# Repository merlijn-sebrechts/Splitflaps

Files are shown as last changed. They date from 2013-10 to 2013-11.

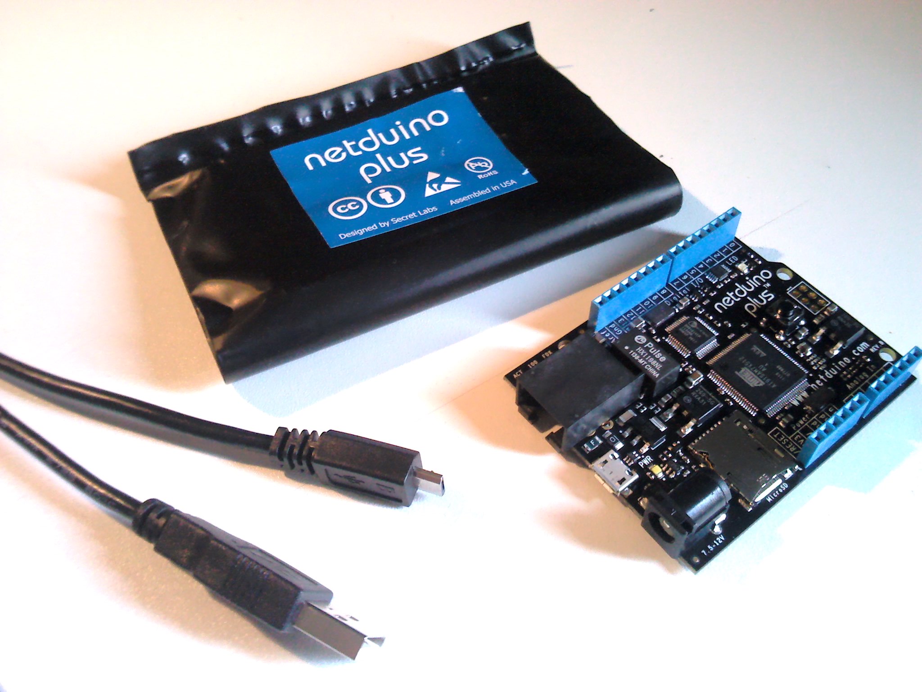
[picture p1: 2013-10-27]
documentation/Media/2012-03-29 13.55.59.jpg

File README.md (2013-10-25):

Splitflaps
==========
This project contains all the technical information I have from the SPLITFLAPS project.

I started this project as part of my studies, an continued to work on it after my studies. However, due to lack of time, I stopped working on it.

related:
http://splitflaps.wordpress.com/
http://www.0x20.be/Project_Flappers
https://www.youtube.com/user/Galgaleshe/videos

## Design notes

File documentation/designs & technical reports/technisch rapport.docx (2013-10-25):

# Microcontroller

## Netduino+

Netduino+ is een arduino microcontroller met het .net micro framework er op. Dit staat toe om je programma’s op het .net framework te laten draaien. Je kan daardoor programmeren in visual C# en alle andere talen ondersteund door het .net micro framework.

## .NET micro framework

Dit is een lichtere, kleinere versie van het .net framework. Doordat het zo licht is word bepaalde .net functionaliteit, zoals generische lijsten, niet ondersteund.

# Programma

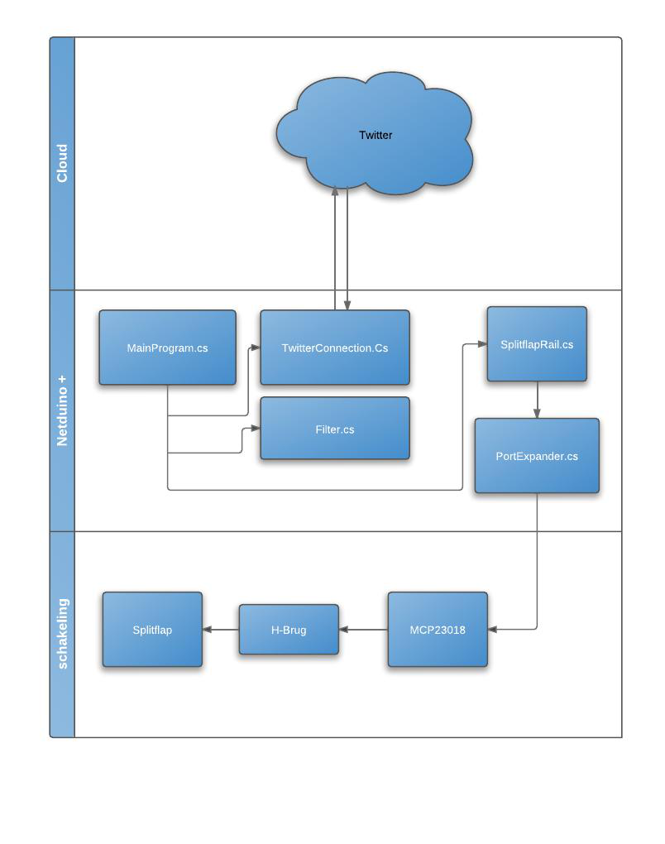
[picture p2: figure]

## Afhalen van Twitter

Dit deel wordt afgeschermd in de klasse TwitterConnection, allereerst wordt de klasse aangemaakt met een hashtag, deze wordt aan de zoekquery toegevoegd

(vb. http://search.twitter.com/search.json?q=%23ikdoeict)

Er zijn verschillende methoden gemaakt voor de zoekquery aan te passen zoals rpp (results per page) en since_id.

Deze methoden roepen een HttpWebRequest op met de URL, de HttpWebRequest zorgt ervoor dat we de query uitvoeren op de twitter server, en we nemen een antwoord op met WebResponse.

Het resultaat van die WebResponse, een json, wordt geparsed door een nieuwe methode,
het parsen gebeurd door middel van IndexOf en Substring.

Alle resultaten van de query (of als results per page = 1 (&rpp=1)) worden in een ArrayList geplaatst en doorgegeven aan de bovenliggende methoden, en die geeft ze dan terug aan de main loop.

## Filter

Deze klasse leest filter.txt in dat op een SD kaart staat. In dit tekst bestand staan alle woorden die verboden zijn in een tweet. Eerst wordt de tekst uit een tweet object gehaald. Vervolgens worden de woorden gesplit en vergeleken met de slechte. Wanneer er een overeenkomst is wordt de tweet niet gebruikt.

Daarna wordt ook op de leestekens gefilterd omdat de splitflaps maar beperkte tekens bevatten. Wanneer er een teken voorkomt wordt deze vervangen door een spatie (lege flap). Vervolgens wordt de tweet tekst opnieuw opgebouwd. Uiteindelijk wordt er een tweet object gereturned.

## Aansturing schakeling

### I2CPlug

Deze klasse voorziet alle functionaliteit van een I2C device. Lezen en schrijven + lezen en schrijven van een register. Deze klasse is gebruikt de repeated-start-bit functionaliteit en is dus niet geschikt voor I2C apparaten die dat niet ondersteunen. De clock-rate wordt automatisch gezet op 400Kh.

### PortexpanderPlug

Deze klasse erft over van de I2CPlug klasse en voorziet alle functionaliteit om de MCP23018 aan te sturen. In de contructor worden de pinnen automatisch op output gezet. Input is niet mogelijk.

Je geeft het adres van de chip mee met de constructor:
PortExpanderPlug(0x20);

Je schrijft een byte naar de pinnen (bit 0 = pin 0). Je geeft de kant van de MCP (A of B)

plug.WriteToPins(byte, Side);

Interne pullup wordt NIET aangezet, je moet die dus zelf nog aanzetten.

### SplitflapConfig

Deze klasse houdt data van de splitflap bij. De beschikbare karakters en hun plaats worden statish bijgehouden in de klasse. Verder wordt de plaats van de splitflap in de schakeling bijgehouden ahv portexpander adres, zijde van de portexpander en bit van de portexpander.

Het huidig getoonde karakter van de splitflap wordt ook bijgehouden. Bij het aanpassen van deze waarde wordt automatisch gekekekn of de splitflap een volledige toer heeft gemaakt. De waare wordt dan op 0 gezet.

### SplitflapRail

Maakt een array van SplitflapConfig-objecten.

De splitflap wordt 1 stap verzet door de betreffende bit van de portexpander te toggelen. Momenteel wordt iedere splitflap apart verzet. Na iedere bit te verzetten moet er een periode gewacht worden tot de flap mechanisch op de volgende positie staat. Dit stond eerst op 50ms maar we hebben de wachttijd moeten vergroten naar 100ms omdat de flaps die er het slechtst aan toe waren anders niet mee konden.

De code kan geoptimaliseerd worden alle splitflaps na elkaar een stap te laten verzetten en pas daarna te wachten. De wachttijd zal dan gelijk zijn aan "normale wachttijd"/"aantal splitflaps"

je maakt een splitflaprail object en geeft de initiele staat mee aan de constructor

SplitflapRail(initialState);

Je geeft de splitflaprail een nieuwe text tonen

rail.show(nieuweTekst);

# Sturing

## MCP23018 port expander

We hebben voor de MCP23018 gekozen omdat deze 16 poorten heft en via het I2C protocol werkt.

De MCP heeft een configureerbaar adres. De eerste 4 bits van het adres zijn statisch. De laatste 3 bits van het adres worden bepaald door de spanning aan de adres-pin.

### I2C protocol

We hebben gekozen voor een chip die werkt met het I2C protocol ipv het SPI protocol. Het SPI protocol is niet bedoeld om een groot aantal slaves te hebben terwijl het I2C daar speciaal voor gemaakt is.

### Schakeling

Het I2C werkt dmv open drain collectors. Ipv een positieve spanning te geven bij logische 1 drainen ze de aanwezige positieve spanning bij een logische nul. Dit om verschillen in de klok van verschillende masters op te lossen. Dit zorgt er wel voor dat alle ingangen en uitgangen een pull-up weerstan nodig hebben. Deze zet de spanning op het logisch-1 voltage als ze niet wordt gedraint

De MCP23018 heeft een inwendige pull-up weerstand aan zijn uitgangen. Deze kan aangezet worden door register GPPU op 255 te zetten. Iedere bit van GPPU zet de desbetreffende GPIO-pull-up resistor aan. We dit echter niet gebruiken. Het I2C protocol van netduino werkt op 3.3V. De MCP moet dus ook op 3.3V gevoed worden. De H-bruggen werken echter op 5V. We zetten dus een pull-up resistor van 5V aan de poorten zodat de MCP, gevoed op 3.3V, een output heeft van 0V-5V.

### Digitale aansturing

De MCP werkt dmv de repeated start bit. Eerst wordt de startbit doorgestuurd gevolgd door het adres van het register dat je wil aanspreken. De startbit wordt daarna nog eens herhaarld gevolgd door een byte met de waarde die het register moet krijgen.

De registers kunnen op 2 manieren aangesproken worden: byte mode en sequential mode. In byte mode zijn de registers 0x00 tot 0x07 voor configuratie van kant A en 0x08 tot 0x15 voor configuratie van kant B. Op deze manier is de MCP compatibel met code geschreven voor een 8-bit port expander. Wij gebruiken echter sequential mode. Daarbij zijn alle even registers voor configuratie van kant A en alle oneven registers voor configuratie van kant B. voor deze stand zet je IOCON op 0.

Via het GPPU kunnen we de interne pull-ups aanzetten, maar die functionaliteit gebruiken we niet.

IODIR zet je op 0x00 om de pinnen als output in te stellen.

## Splitflap

De splitflap bestaat uit een stappenmotor en een sensor

### Stappenmotor

De motor in de splitflap is een stappenmotor. Iedere keer de spanning omgewisseld word verspringt hij 1 flap. De frequentie waarmee de spanning omgewisseld word moet hoog genoeg zijn om de motor toe te laten de volledige stap te verspringen. Doordat het materiaal niet meer in topconditie is moet er tot 100ms gewacht worden voor de spanning mag omgeschakeld worden. Dit zorgt ervoor dat de flaps zeer traag verspringen.

### Sensor

De sensor geeft aan wanneer de flap op 0 staat. Het grootste deel van de sensors werkt echter niet meer waardoor we die niet kunnen gebruiken.

## H-brug

De spanning over de splitflap wordt geregeld door de L293D H-brug

### Schakeling

De H-brug wordt gevoed op 5V. input 1, 2, 3 en 4 werken ook op 5V. output 1, 2, 3 en 4 geven zelfde spanning als VS bij logische 1.

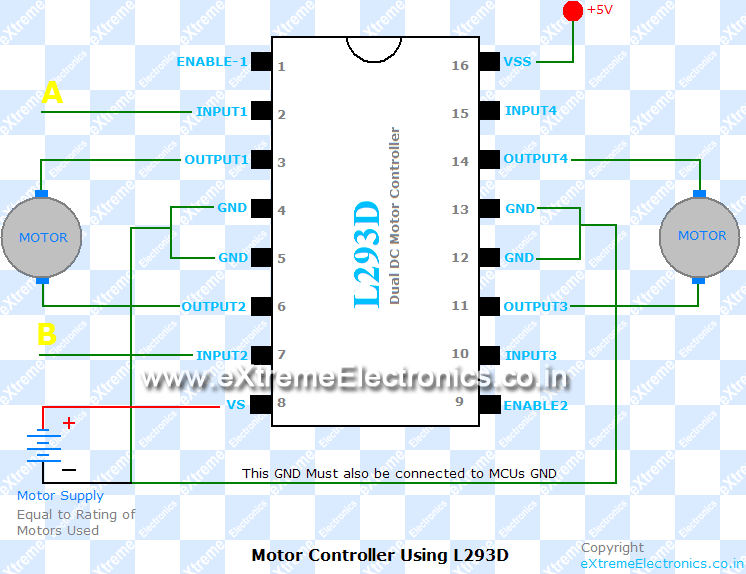
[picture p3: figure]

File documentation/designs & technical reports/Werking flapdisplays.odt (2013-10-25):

# Basiswerking van de flapdisplays.

## De letters verzetten.

Het display bestaat uit een soort tweeweg elektromagneet. Dat wil zeggen dat niet bij elke puls een letter opgeteld wordt, maar enkel bij ompoling: bij een eerste positieve puls gaat hij een letter vooruit, daarna is een negatieve puls nodig voor de volgende letter (een tweede positieve puls heeft geen effect), opnieuw een positieve puls voor de derde letter, enzovoort.

Het aansturen van de letters lukt goed met 12V gelijkspanning. Ik weet niet of dit de officieel vereiste spanning is, maar het werkt zonder haperen (het display moet uiteraard wel netjes verticaal staan).

Het ompolen wordt gerealiseerd door de Arduino een H – brug te laten aansturen. Hier wordt een IC L293D voor gebruikt, die 2 dergelijke H bruggen bevat. Zo’n L293D zou dus 2 letters kunnen aansturen. Hiervoor zijn 2 Arduino uitgangen nodig per letter. Zie figuur, afkomsting van

http://www.freewebs.com/isuru-c/motor%20driver.JPG

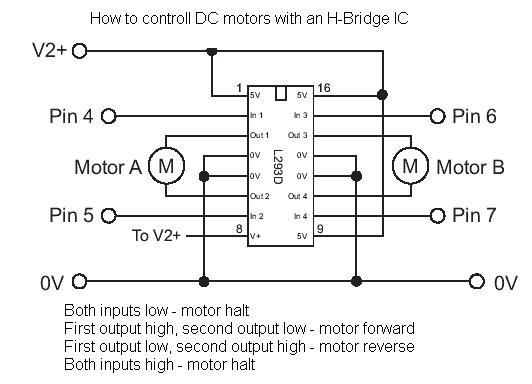
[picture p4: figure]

Figuur 1: De aansluiting van de 2 H bruggen in één L293D. Eén letter kan gestuurd worden door Arduino uitgangen te hangen aan pinnen 4 en 5, de andere met uitgangen aan pinnen 6 en 7. Het voorbeeld hier is voor sturing van 2 stappenmotors, maar het schema voor de flapdisplay is identiek. Alleen de softwarematige sturing van de Arduino uitgangen verschilt, en de flapdisplay kan alleen vooruit gaan, niet achteruit. V2+ is 12 volt. De vereiste stroom is afhankelijk van het formaat van de letter, en draait rond enkele tientallen milliampères.

Het printontwerp voor de L293D is in principe niet zo moeilijk, vermits er enkel aansluitingen en doorverbindingen nodig zijn. Het IC bevat intern ook al beveiligingsdiodes om zichzelf te beschermen tegen inductiespanningen die ontstaan bij het uitschakelen van de elektromagneet, dus zelfs dat moet niet extra toegevoegd worden.

Om één of twee letters te sturen zal een L293D zonder enige extra componenten volstaan. Maar als je begint met grotere aantallen, zou ik sterk aanraden van de voeding van elke afzonderlijke letter van een ontkoppelcondensatortje te voorzien, om elektromagnetische storingen en onderlinge beïnvloeding via de voeding te beperken. Dat betekent: per letter een condensatortje tussen de 12V en de nul, en fysiek zo dicht mogelijk bij de L293D geplaatst. De exacte waarde is moeilijk te zeggen, maar ergens tussen de 0,1 en 1 µF zou moeten volstaan (liever te groot dan te klein, maar dat is ook wat duurder natuurlijk). Het is vooral belangrijk dat hiervoor de ruimte en soldeereilandjes op de print voorzien worden, de optimale waarde kan je later experimenteel vaststellen. Het is zelfs mogelijk dat blijkt dat je die condensator kan weglaten, maar ik zou het risico niet nemen.

## Vaststellen van de huidige positie.

Tenslotte is er de kwestie van positiebepaling (waar begint het alfabet?). Op het display draait een klein armpje mee waarop een minuscuul magneetje is bevestigd. Op een vaste positie is een magnetische sensor (Hall sensor) aangebracht, zodanig dat deze het passeren van het magneetje detecteert. Telkens als het display volledig rond is (na 360°) geeft dit een signaal af aan één Arduino ingang. Op dat moment is de absolute positie bekend, de andere posities zijn een kwestie van optellen vanaf deze positie, tot het magneetje weer langs de sensor passeert en de teller weer op 1 kan gezet worden.

Door telkens op 1 te zetten bij passeren van de startpositie kan ook gezorgd worden dat de letters vrijwel altijd in de pas blijven (ook als door een externe oorzaak of hapering eens een letter zou overgeslagen worden: zelfs als dan eens een foute letter getoond wordt, zal de daaropvolgende toch weer juist zijn, als de oorzaak van de hapering weggenomen is ). Gedurende de hele testperiode is trouwens nooit een letter blijven haperen, tenzij het display schuin ligt of als je de letter echt tegenhoudt.

Bij het opstarten van het systeem zoekt de software automatisch naar de startpositie, en zet het display op een blanco flap.

Samengevat: per letter 2 Arduino uitgangen en 1 ingang nodig. Per 2 letters een L293D nodig.

# Een print voor meerdere letters.

Een Arduino Mega heeft bijvoorbeeld 16 analoge ingangen en 54 digitale in/uitgangen. Om een letter te sturen kan je zowel een analoge ingang als een digitale ingang gebruiken. Je zou dus in theorie 23 letters met één Arduino Mega kunnen sturen: je gebruikt dan de 16 analoge ingangen en nog 7 digitale pinnen als ingang. Blijven 47 pinnen over als digitale uitgang, eentje op overschot dus (kan evt gebruikt worden voor een status ledje of zo).

Dit veronderstelt echter dat de tekst die naar de flaps gestuurd wordt intern in de Arduino is geprogrammeerd. Indien je de tekst extern wil toevoeren moet je daar natuurlijk een paar ingangen voor reserveren, dus dat betekent een paar letters minder dan de theoretische 23. Het hangt af van het exacte systeem dat je hiervoor gebruikt (serieel, ethernet?), maar 20 letters per Mega lijkt me in elk geval haalbaar.

Op zo’n print voor 20 letters zouden naast de Arduino Mega dus ook 10 stuks L293D een plaatsje moeten krijgen, en natuurlijk alle connectors voor flap displays (4 pinnen per letter: 2 voor elektromagneet, 3 voor positiesensor), voeding voor de Arduino, voeding voor de letters (12V) en stuursignaal. Het lijkt me ook verstandig om een lijntje of 2 voor terugmelding te voorzien, zodat je op afstand kan checken of de hele print wel werkt (vb. of de stroom niet is uitgevallen).

Ik zou de Arduino als opsteekprint op de basisprint zetten, zodat je hem er gemakkelijk kan afhalen of verwisselen. Dat heeft voordelen bij het programmeren en eventueel oplossen van probleempjes. Zeker ook de Arduino’s apart voeden, niet met de 12V spanning die voor de flapdisplays is bedoeld, anders riskeer je onderlinge beïnvloeding.

Qua kosten zou het ideaal zijn als dit alles op een print van eurokaartformaat (100 x 160 mm) zou geraken, maar eerlijk gezegd ben ik niet zeker of dat zal lukken. Dat zal pas blijken als iemand het printontwerp echt probeert te maken.

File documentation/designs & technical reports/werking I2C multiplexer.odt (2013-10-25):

I2C port expander

Korte inhoud:

1. De master stuurt het adres van de slave door .
2. De slave antwoord met “huh?”.
3. De master stuurt de data door.
4. De slave zegt “ah!”.
5. De master zegt STOP.

Vergelijk het met een netwerk met een hub. Iedereen die op de bus zit ziet de data maar enkel de slave met het juiste adres reageert op de data.

Bij een multiplexer zal dus iedere slave een aparte output pin zijn. Je stuurt dan eerst het adres van de pin door waarna je de toestand van de pin doorstuurt.

je hebt een I2c module nodig op je microcontroller (aanwezig op netduino maar hoeveel?) Die bestaat uit 2 pinnen.

Een adres bestaat uit 8 of 10 bits maar bepaalde delen ervan kunnen niet gebruikt worden (vergelijk het met broadcast) WELKE???, hoeveel per bus??

Als er meerdere I2C bussen op het netduino board zitten kunnen we meerdere I2c “netwerken” maken, hebben we veel meer adressen. (juij, maar hebben we meerdere I2C bussen?)

De slave is hier een port expander IC. KAN JE DE ADRESSEN VAN DE PORT EXPANDER INSTELLEN OF ZIJN ZE HARD CODED?

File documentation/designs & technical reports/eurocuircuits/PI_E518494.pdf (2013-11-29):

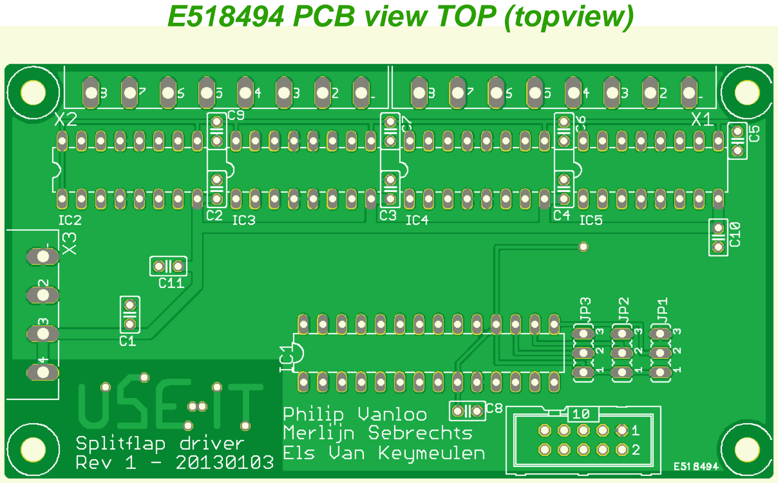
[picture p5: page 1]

### E518494 PCB view TOP (topview)

E518494 TOP layer Image (topview)

E518494 BOTTOM layer Image (topview)

E518494 PCB view BOTTOM (bottomview)

# E518494 PCB Mechanical view (topview)

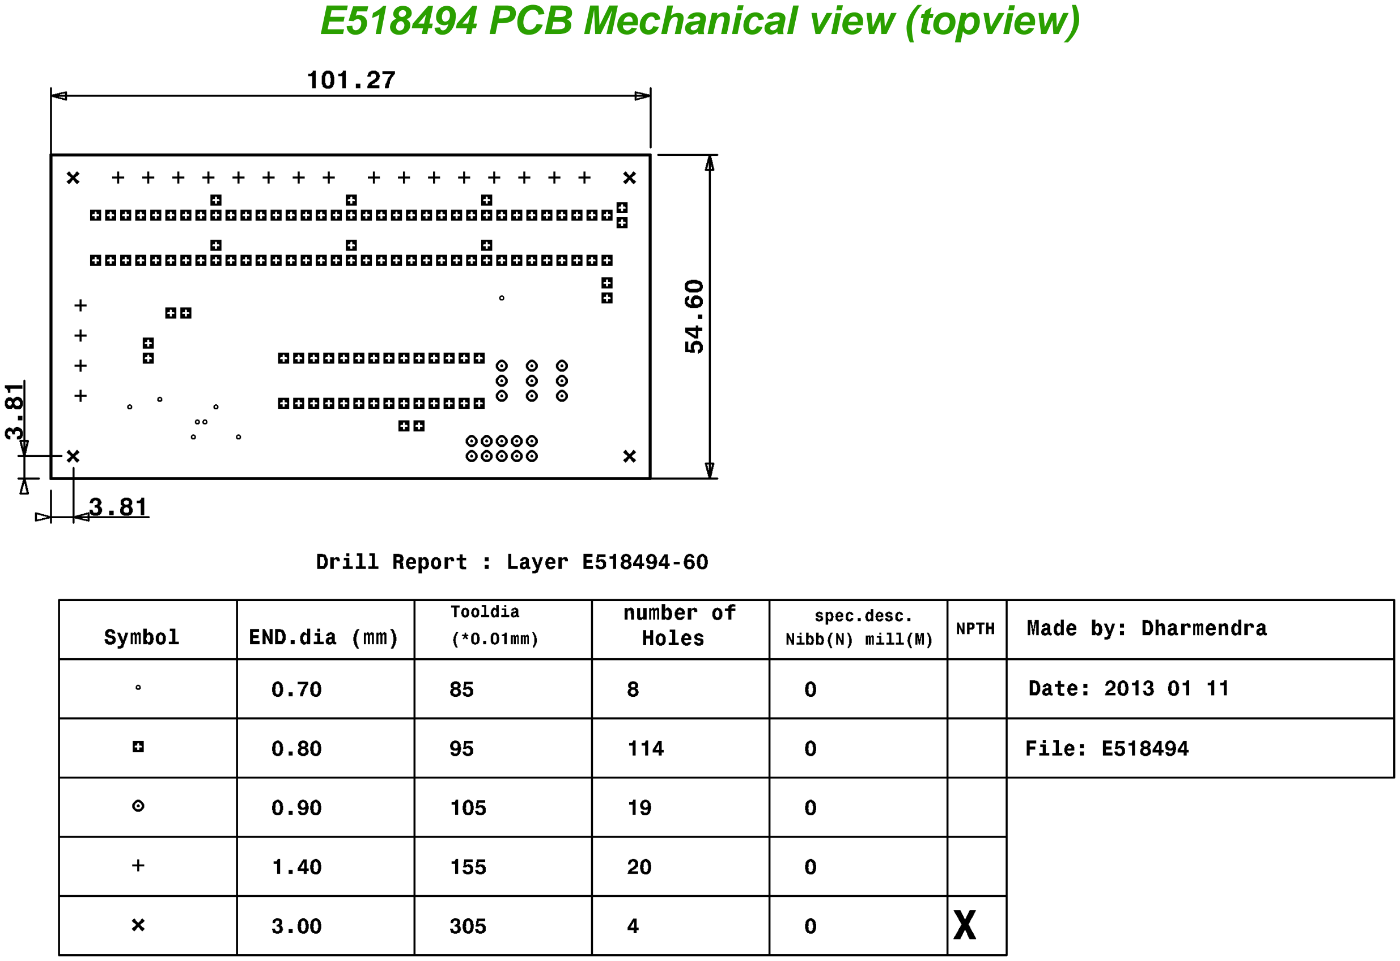
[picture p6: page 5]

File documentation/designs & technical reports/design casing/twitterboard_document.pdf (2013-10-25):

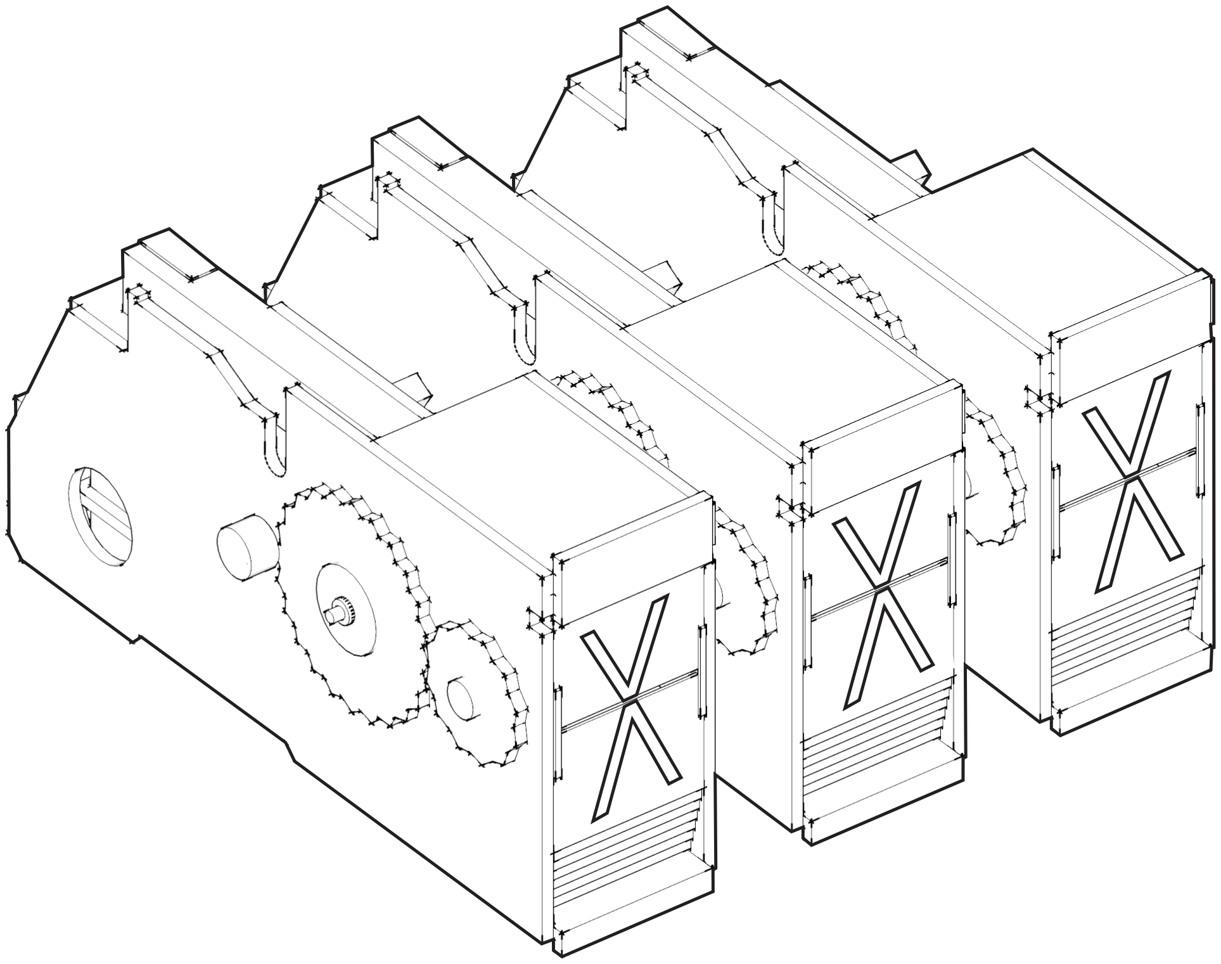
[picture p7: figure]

# TWITTER BOARD shelf design

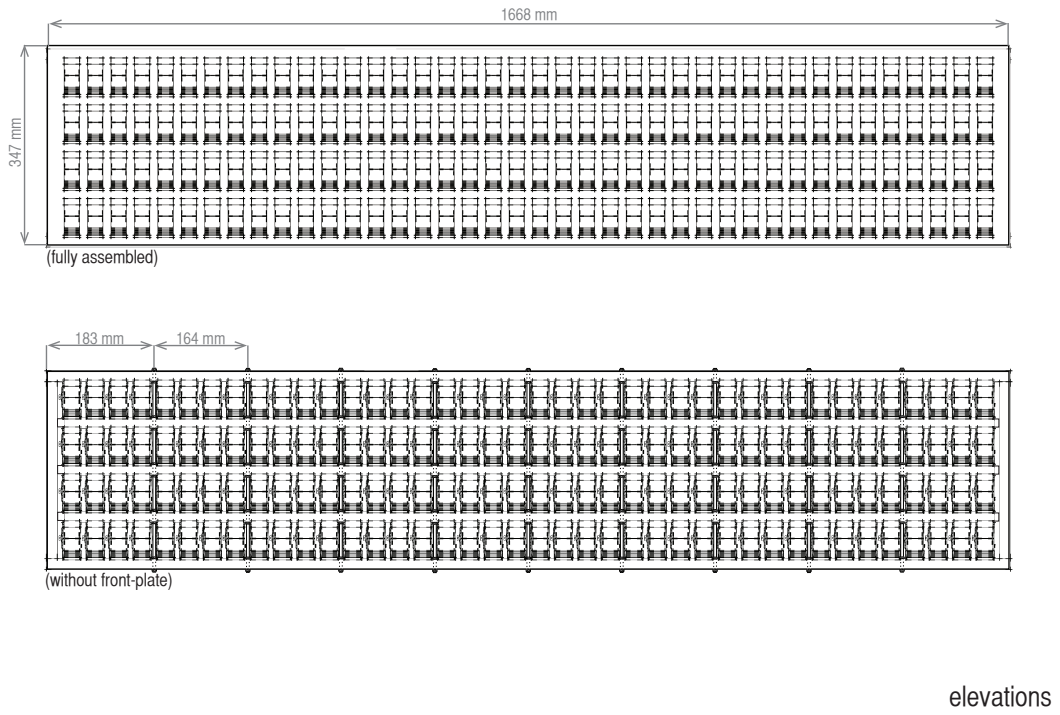
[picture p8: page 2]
(fully assembled); elevations

(without front-plate)

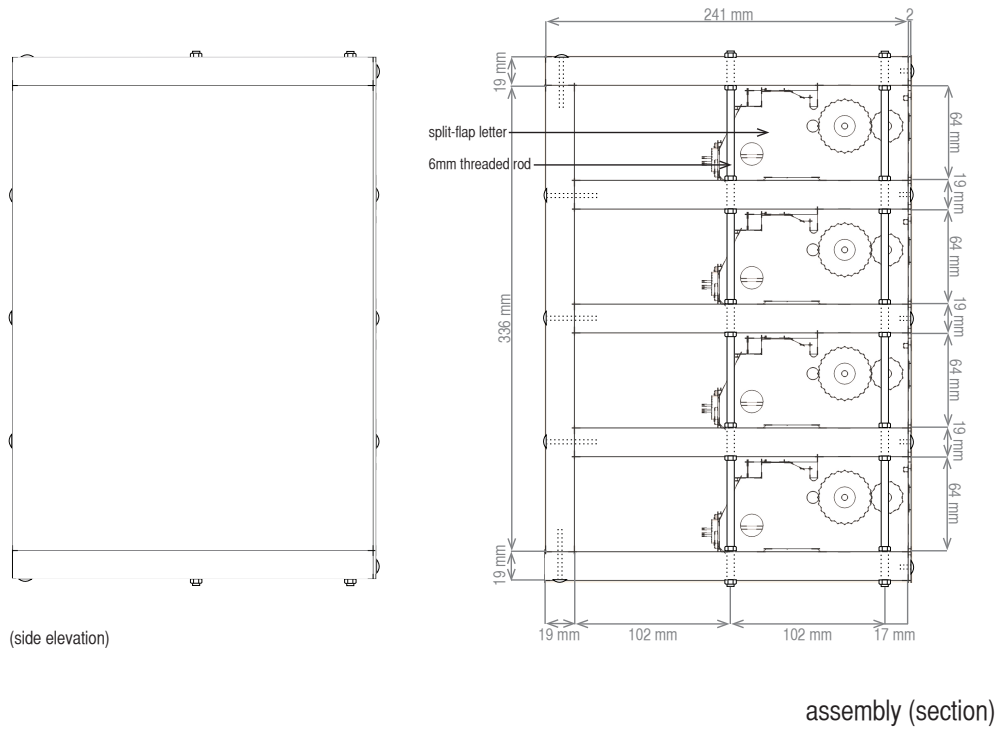
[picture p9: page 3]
assembly (section); (side elevation)

split-flap letter
6mm threaded rod

d
e

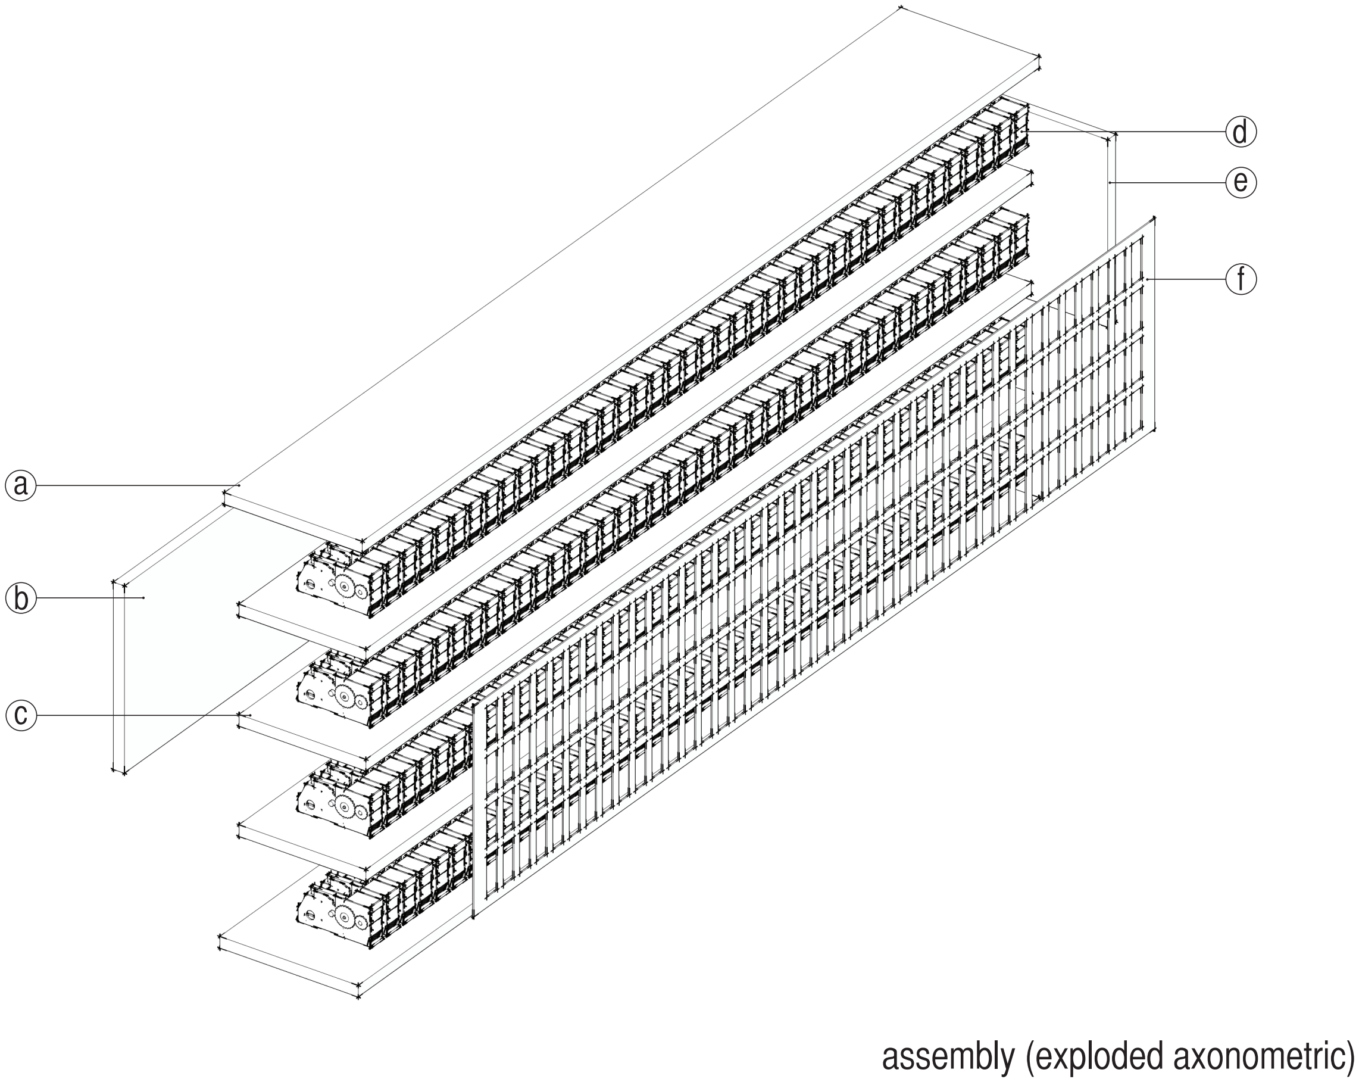
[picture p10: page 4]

## assembly (exploded axonometric)

b

c

a

f

## components

back plate x 1

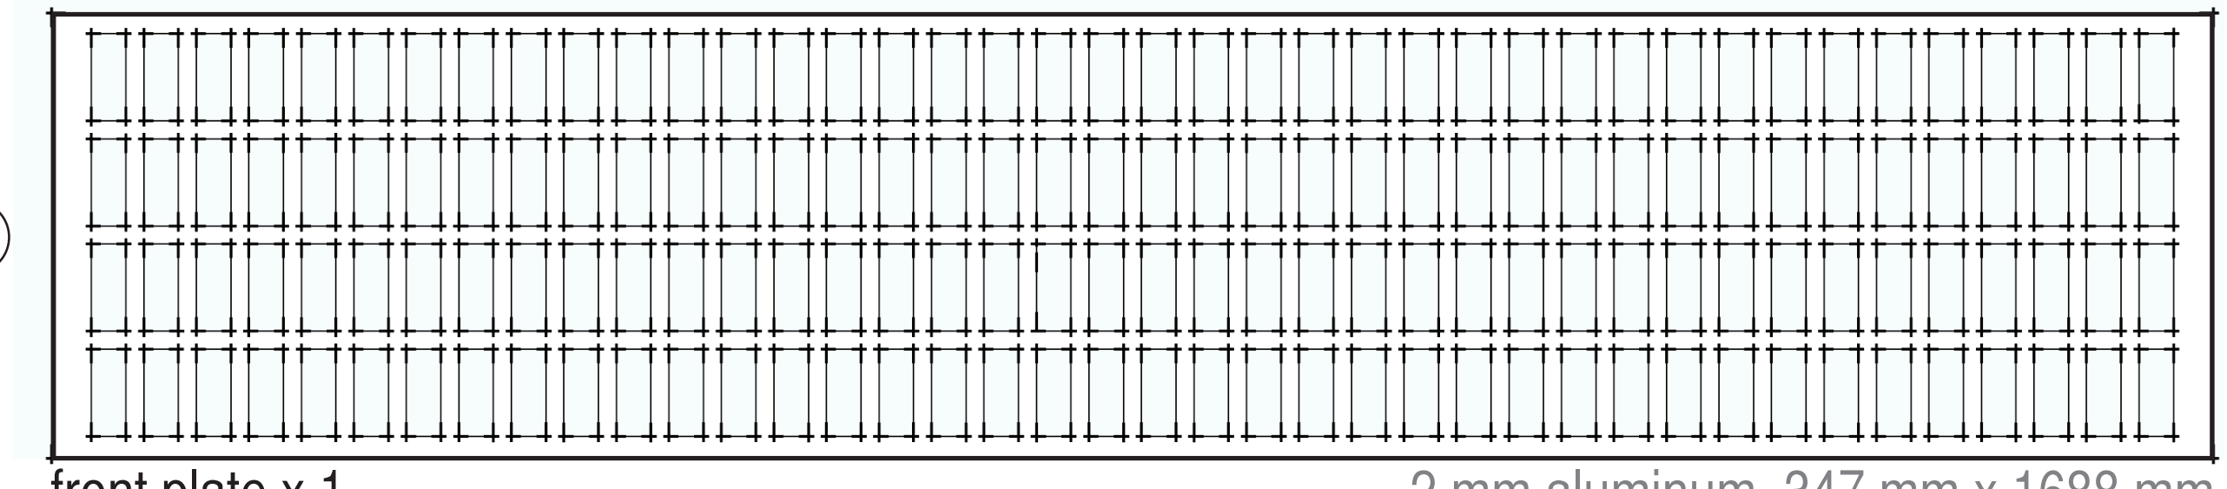
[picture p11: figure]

front plate x 1

split-flap letter x 160

shelf x 3

top/bottom plate x 2

side plate x 2

a

b

c

d | e

f

19 mm mdf, 240 mm x 1678 mm

19 mm mdf, 309 mm x 1650 mm

19 mm mdf, 221 mm x 1650 mm

19 mm mdf, 240 mm x 309 mm

2 mm aluminum, 347 mm x 1688 mm

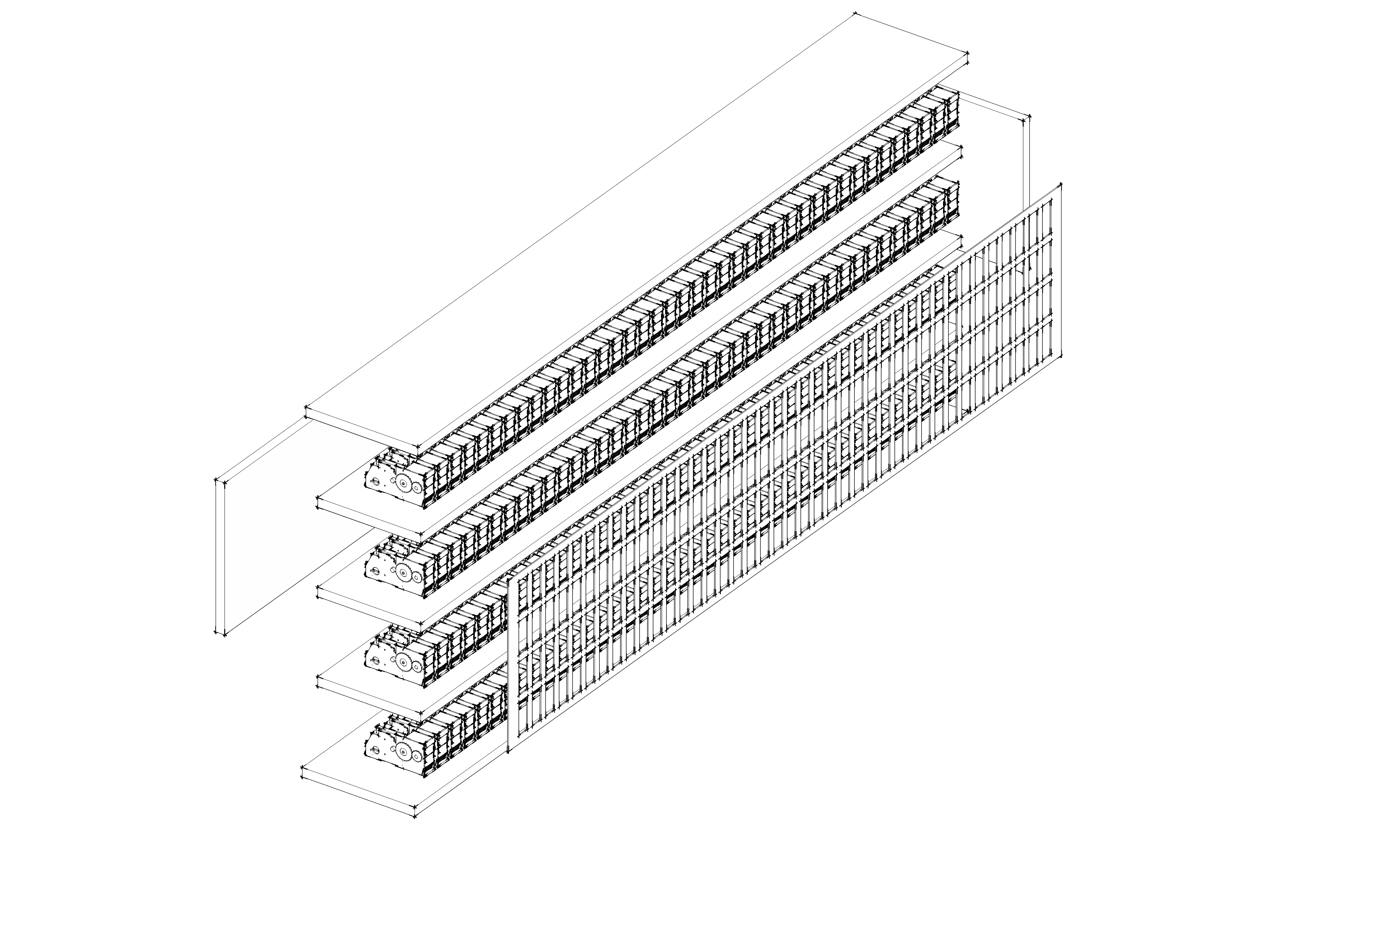
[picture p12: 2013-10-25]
documentation/designs & technical reports/design casing/twitterboard_explodedaxo.jpg

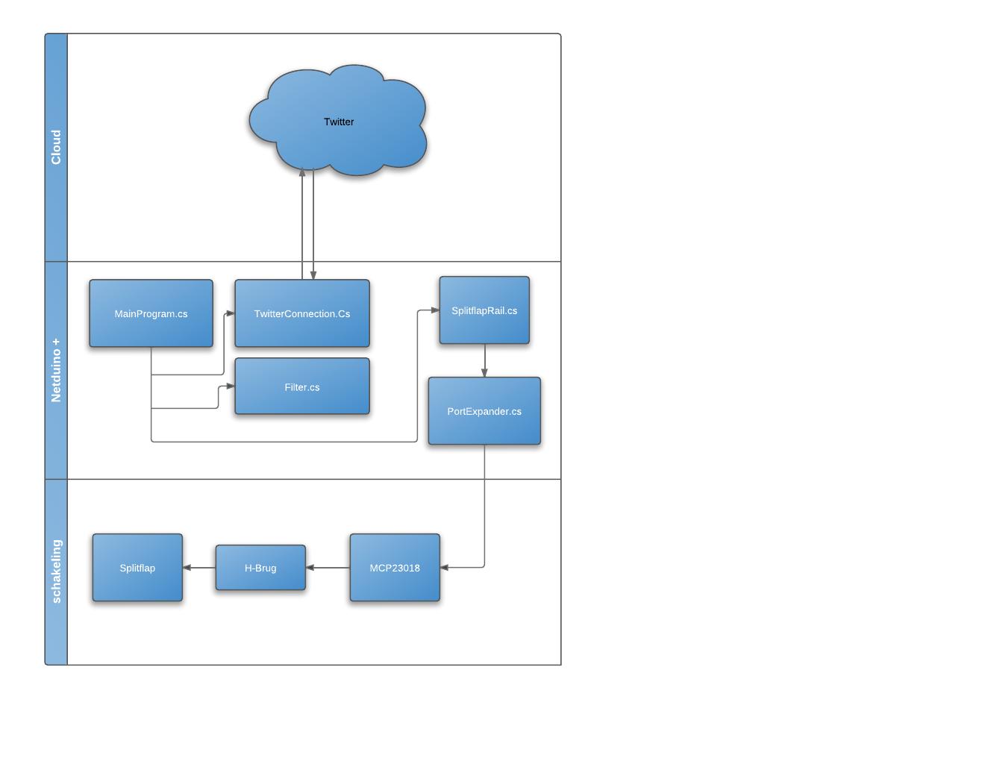
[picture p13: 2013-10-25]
documentation/designs & technical reports/Splitflaps.jpeg

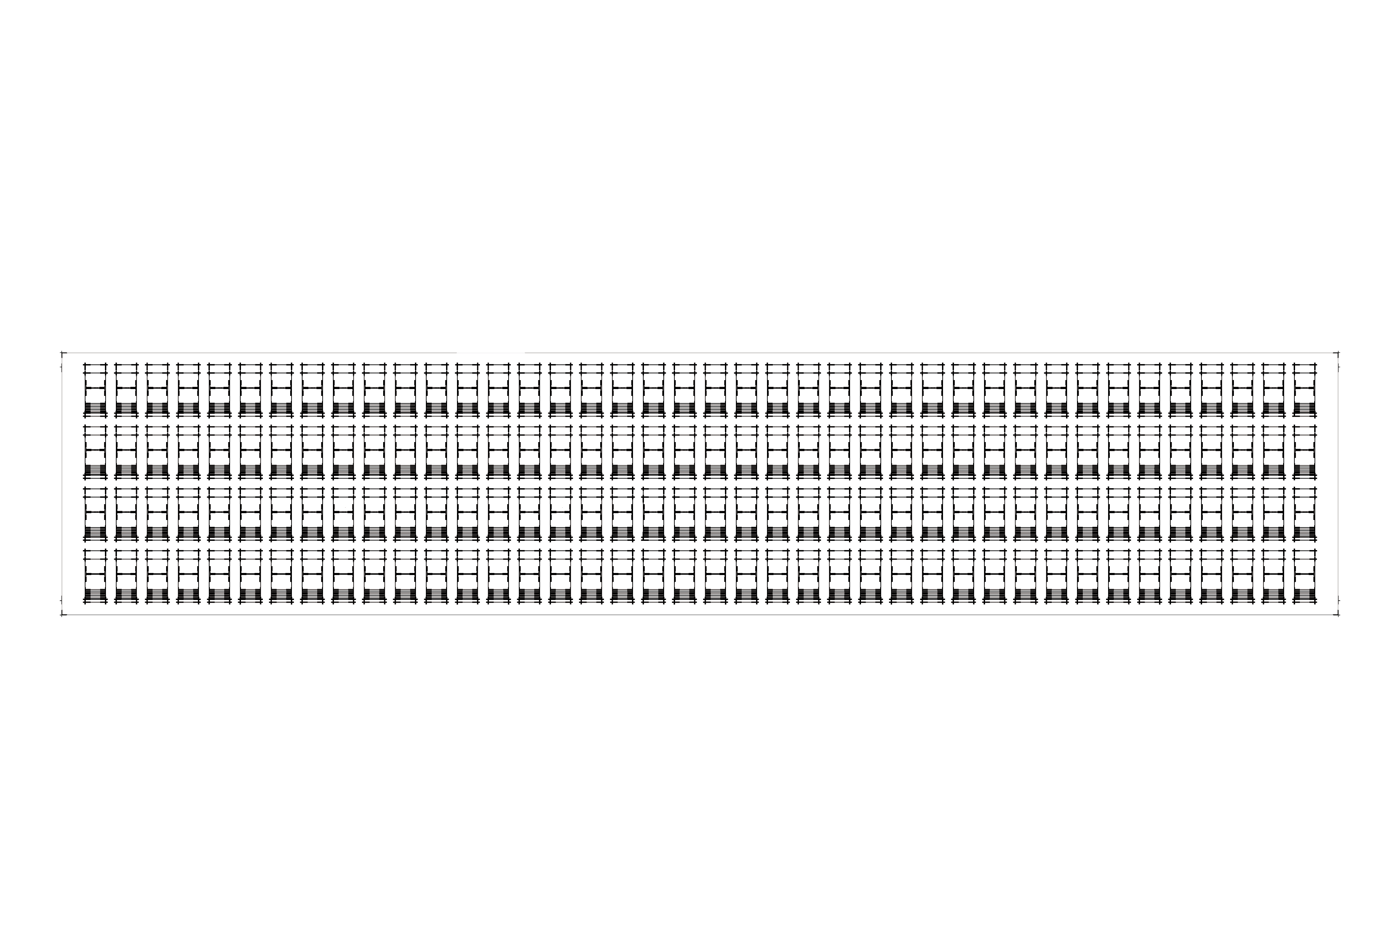
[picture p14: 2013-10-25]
documentation/designs & technical reports/design casing/twitterboard_elevation.jpg

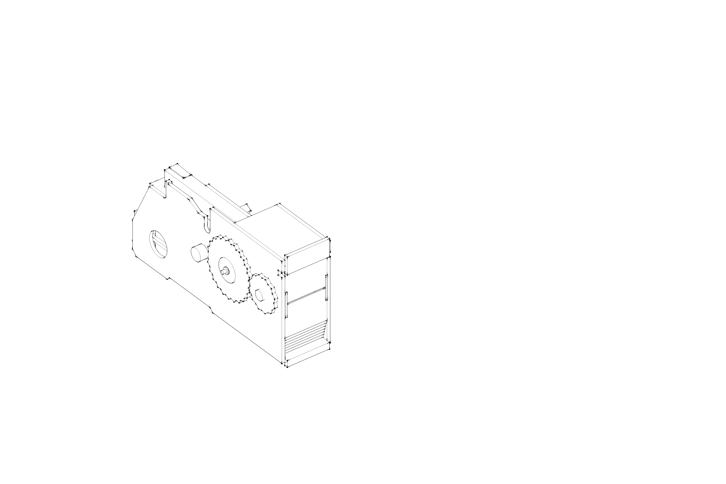
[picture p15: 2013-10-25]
documentation/designs & technical reports/design casing/twitterboard_switchaxo.jpg

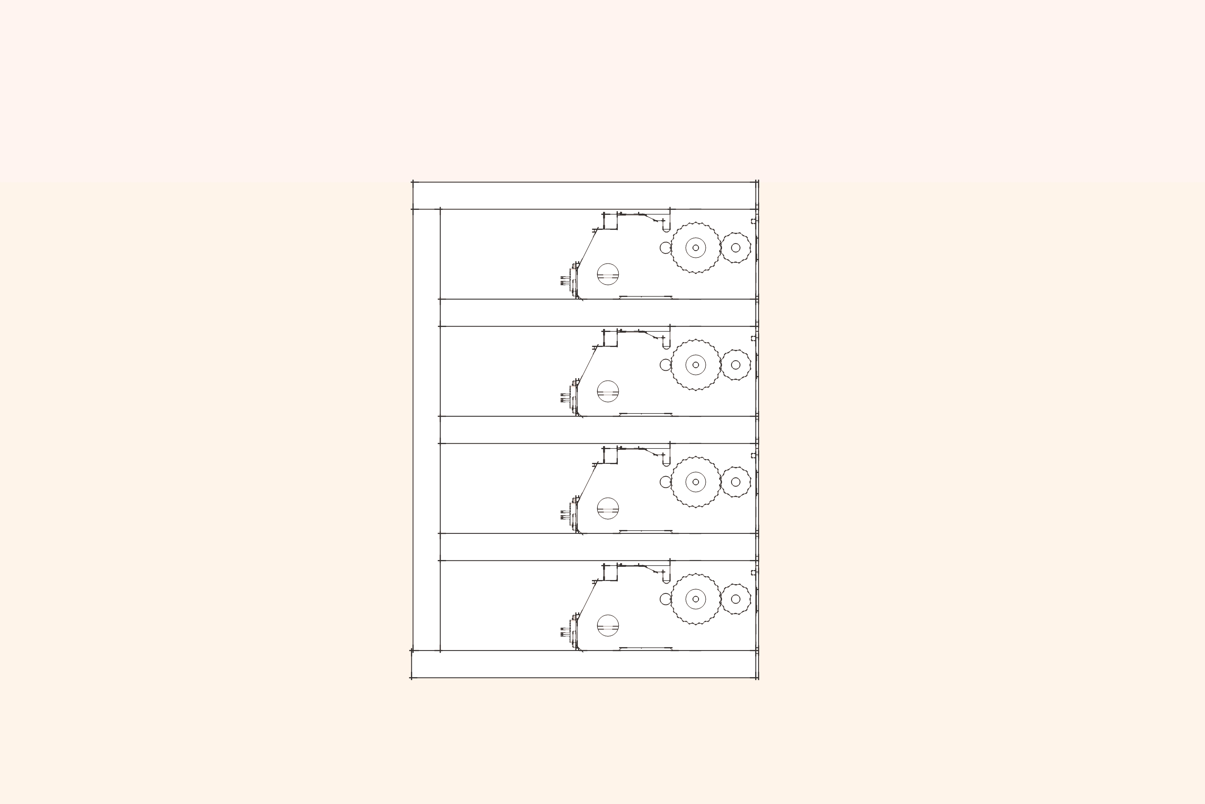
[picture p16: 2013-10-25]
documentation/designs & technical reports/design casing/twitterboard_section.jpg

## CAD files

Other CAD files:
documentation/designs & technical reports/design casing/twitterboard_drawings.dwg
documentation/designs & technical reports/design casing/twitterboard_switchaxo.skp
documentation/designs & technical reports/design casing/twitterboard_switchaxo~.skp

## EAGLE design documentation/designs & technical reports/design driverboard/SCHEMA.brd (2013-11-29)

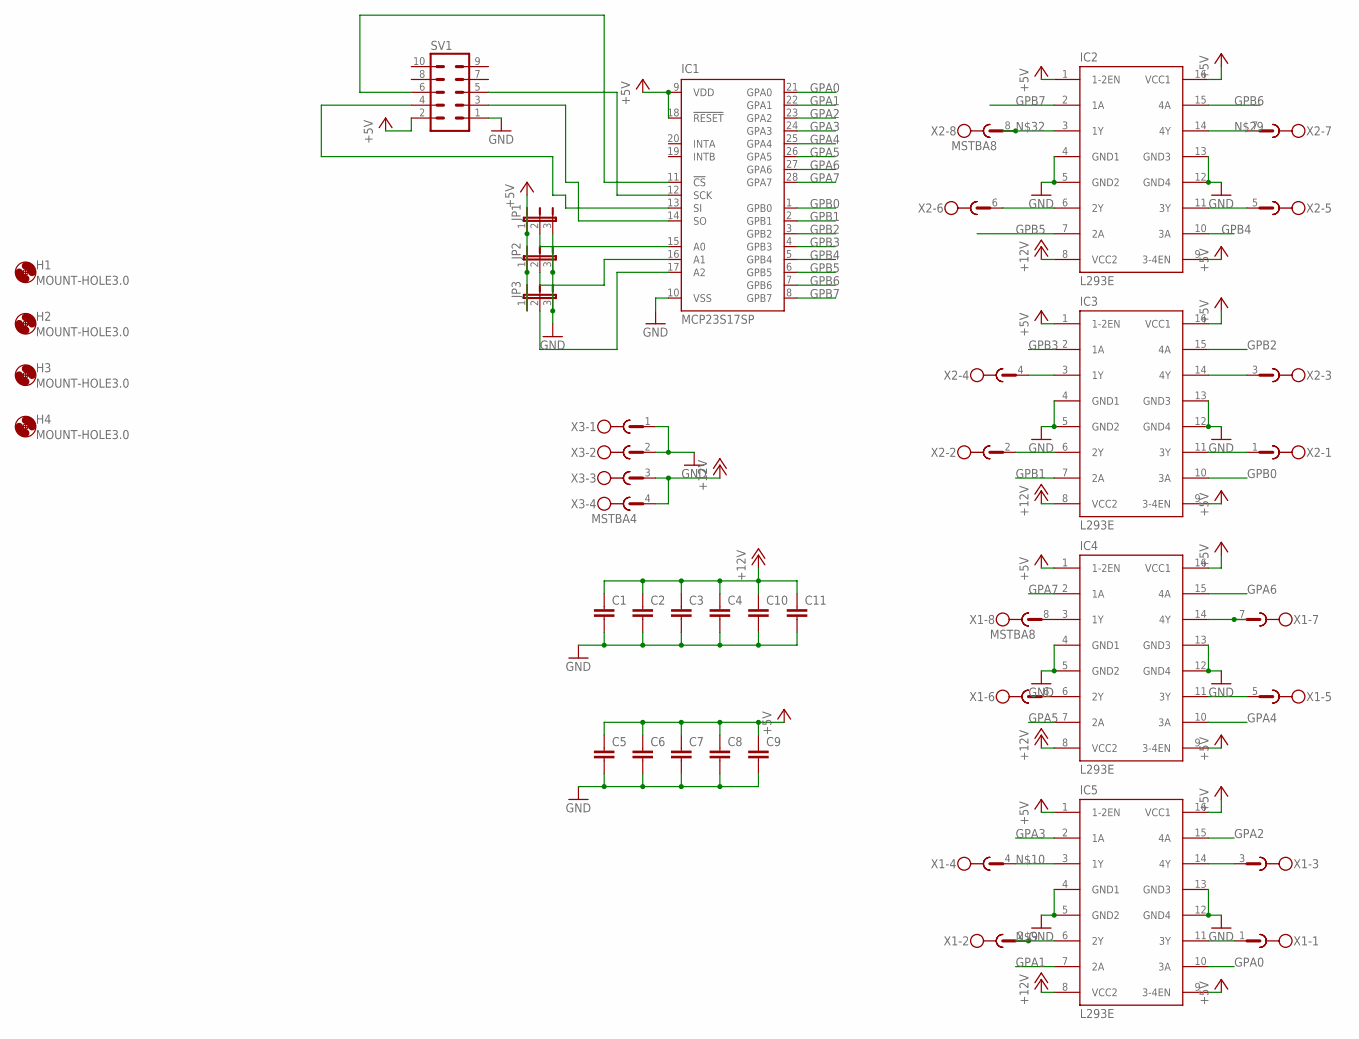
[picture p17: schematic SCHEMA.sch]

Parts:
C1, C2, C3, C4, C5, C6, C7, C8, C9, C10, C11: C-EU025-025X050; C025-025X050
H1, H2, H3, H4: MOUNT-HOLE3.0; 3,0
IC1: MCP23S17SP; DIL28-3
IC2, IC3, IC4, IC5: L293E; DIL16
JP1, JP2, JP3: JP2E; JP2
SV1: ML10
X1, X2: MSTBA8
X3: MSTBA4

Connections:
+5V: C5.1, C6.1, C7.1, C8.1, C9.1, IC1.9 (VDD), IC1.18 (!RESET), IC2.1 (1-2EN), IC2.9 (3-4EN), IC2.16 (VCC1), IC3.1 (1-2EN), IC3.9 (3-4EN), IC3.16 (VCC1), IC4.1 (1-2EN), IC4.9 (3-4EN), IC4.16 (VCC1), IC5.1 (1-2EN), IC5.9 (3-4EN), IC5.16 (VCC1), JP1.1, JP2.1, JP3.1, SV1.2
+12V: C1.1, C2.1, C3.1, C4.1, C10.1, C11.1, IC2.8 (VCC2), IC3.8 (VCC2), IC4.8 (VCC2), IC5.8 (VCC2), X3.3, X3.4
GND: C1.2, C2.2, C3.2, C4.2, C5.2, C6.2, C7.2, C8.2, C9.2, C10.2, C11.2, IC1.10 (VSS), IC2.4 (GND1), IC2.5 (GND2), IC2.12 (GND4), IC2.13 (GND3), IC3.4 (GND1), IC3.5 (GND2), IC3.12 (GND4), IC3.13 (GND3), IC4.4 (GND1), IC4.5 (GND2), IC4.12 (GND4), IC4.13 (GND3), IC5.4 (GND1), IC5.5 (GND2), IC5.12 (GND4), IC5.13 (GND3), JP1.3, JP2.3, JP3.3, SV1.1, X3.1, X3.2
GPA0: IC1.21 (GPA0), IC5.10 (3A)
GPA1: IC1.22 (GPA1), IC5.7 (2A)
GPA2: IC1.23 (GPA2), IC5.15 (4A)
GPA3: IC1.24 (GPA3), IC5.2 (1A)
GPA4: IC1.25 (GPA4), IC4.10 (3A)
GPA5: IC1.26 (GPA5), IC4.7 (2A)
GPA6: IC1.27 (GPA6), IC4.15 (4A)
GPA7: IC1.28 (GPA7), IC4.2 (1A)
GPB0: IC1.1 (GPB0), IC3.10 (3A)
GPB1: IC1.2 (GPB1), IC3.7 (2A)
GPB2: IC1.3 (GPB2), IC3.15 (4A)
GPB3: IC1.4 (GPB3), IC3.2 (1A)
GPB4: IC1.5 (GPB4), IC2.10 (3A)
GPB5: IC1.6 (GPB5), IC2.7 (2A)
GPB6: IC1.7 (GPB6), IC2.15 (4A)
GPB7: IC1.8 (GPB7), IC2.2 (1A)
unnamed: IC4.6 (2Y), X1.6
unnamed: IC4.3 (1Y), X1.8
unnamed: IC1.14 (SO), SV1.3
unnamed: IC1.15 (A0), JP1.2
unnamed: IC1.16 (A1), JP2.2
unnamed: IC1.17 (A2), JP3.2
unnamed: IC1.13 (SI), SV1.4
unnamed: IC1.12 (SCK), SV1.5
unnamed: IC5.6 (2Y), X1.2
unnamed: IC5.3 (1Y), X1.4
unnamed: IC1.11 (!CS), SV1.6
unnamed: IC5.14 (4Y), X1.3
unnamed: IC5.11 (3Y), X1.1
unnamed: IC4.14 (4Y), X1.7
unnamed: IC4.11 (3Y), X1.5
unnamed: IC3.14 (4Y), X2.3
unnamed: IC3.11 (3Y), X2.1
unnamed: IC3.3 (1Y), X2.4
unnamed: IC3.6 (2Y), X2.2
unnamed: IC2.14 (4Y), X2.7
unnamed: IC2.11 (3Y), X2.5
unnamed: IC2.6 (2Y), X2.6
unnamed: IC2.3 (1Y), X2.8

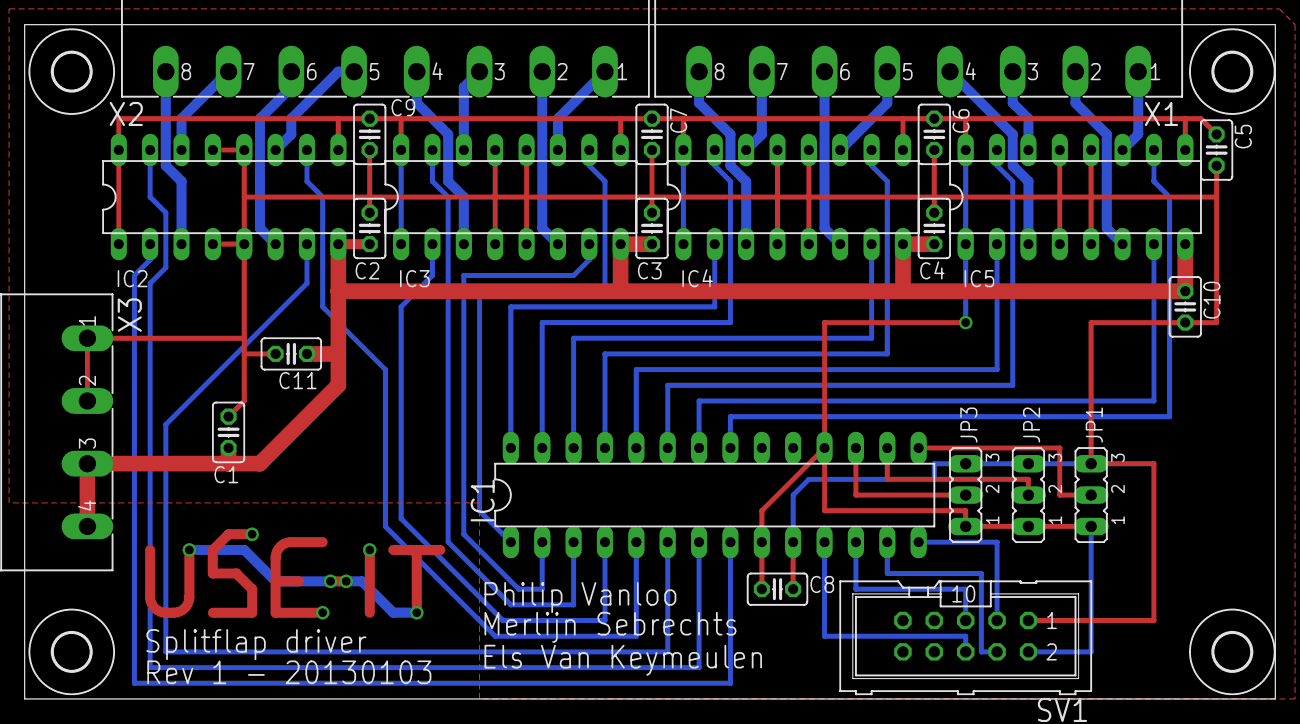
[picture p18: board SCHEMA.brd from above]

Board: 2 copper layers, 101.3 x 54.6 mm, 27 parts (0 on the bottom side), 42 nets.

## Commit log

2013-10-25 changed directory structure, added drawings
    [twitterboard_drawings.dwg, twitterboard_switchaxo.skp, twitterboard_switchaxo~.skp]
2013-10-25 added files from old project
    [twitterboard_drawings.dwg, twitterboard_switchaxo.skp, twitterboard_switchaxo~.skp]
2013-11-29 renamed, because the name was confusing
    [twitterboard_drawings.dwg, twitterboard_switchaxo.skp, twitterboard_switchaxo~.skp]
2013-11-29 added design driverboard
    [SCHEMA.brd, SCHEMA.sch]
